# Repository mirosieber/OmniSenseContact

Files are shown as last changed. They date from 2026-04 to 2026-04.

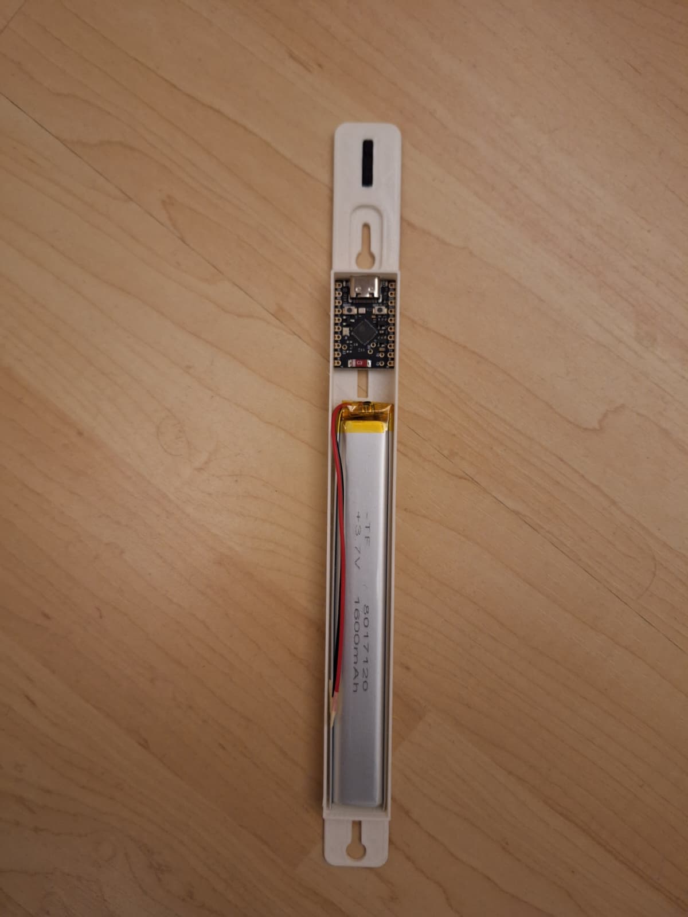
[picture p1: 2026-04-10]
Hardware/Bild1.jpeg

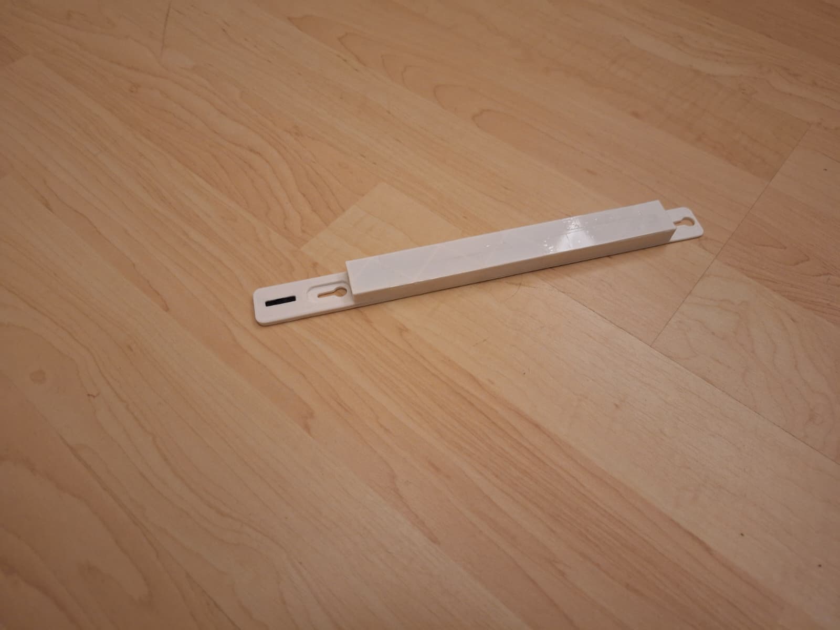
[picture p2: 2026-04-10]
Hardware/Bild2.jpeg

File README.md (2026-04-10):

# OmniSenseContact

A battery-powered Zigbee window/door contact sensor based on the ESP32-C6 Supermini with integrated 1S Li-Po charger.

## Overview

OmniSenseContact is a Zigbee-based window/door contact sensor for smart home automation. Built on the ESP32-C6 Supermini platform, it operates as a Zigbee End Device and communicates with your Zigbee coordinator (such as Home Assistant, Zigbee2MQTT, or other Zigbee hubs).

## Features

- **Zigbee Communication**: Native Zigbee 3.0 support via ESP32-C6
- **Binary Contact Sensor**: Reports open/closed state changes instantly
- **Battery Monitoring**: Real-time battery voltage and SoC reporting
- **Low Power Design**: Deep sleep mode with wake-up on state change or timer
- **Wake-up Sources**: Contact state change (GPIO interrupt), daily timer (24 hours), charger connection detection
- **Battery Protection**: Automatic shutdown at low battery (<10% SoC)

## Hardware Requirements

### Microcontroller
- **ESP32-C6 Supermini**: RISC-V based MCU with native Zigbee support and integrated 1S Li-Po charger
  - 160 MHz single-core processor
  - 512 KB SRAM
  - Built-in Zigbee 3.0 IEEE 802.15.4 radio

### Components
- **Battery**: 1S Li-Ion or Li-Po battery (3.7V nominal)
- **Contact Sensor**: **Normally Closed (NC)** magnetic reed switch or physical contact switch (required for energy efficiency)
- **Voltage Dividers**: For battery and charger detection
  - Battery monitoring: R1: 510kΩ, R2: 1MΩ
  - Charger detection: R1: 510kΩ, R2: 1MΩ

## Pin Configuration

| Pin | Function | Direction | Description |
|-----|---|---|---|
| GPIO 0 | Charger Detection | Input | HIGH when USB charger connected |
| GPIO 1 | Battery Voltage | Analog Input | Voltage divider output |
| GPIO 2 | Contact Sensor | Input (Pull-up) | LOW = closed, HIGH = open |
| GPIO 15 | Status LED | Output | Activity indicator |

## Software Requirements

- **ESP-IDF**: Version 4.1.0 or higher (tested with v5.x)
- **Arduino ESP32**: Version 3.3.2 (included as component)
- **CMake**: Version 3.5 or higher

### Required Components
- **ESP Zigbee SDK**: Included as git submodule

## Installation

### 1. Clone the Repository

```bash
git clone https://github.com/mirosieber/OmniSenseContact.git
cd OmniSenseContact
git submodule update --init --recursive
```

### 2. Install ESP-IDF

Follow the official ESP-IDF installation guide:
https://docs.espressif.com/projects/esp-idf/en/latest/esp32c6/get-started/

### 3. Build and Flash

```bash
idf.py build
idf.py -p /dev/ttyUSB0 flash monitor
```

Replace `/dev/ttyUSB0` with your serial port.

## Configuration

### Zigbee Configuration

```cpp
Manufacturer: "Miro Sieber"
Model: "OmniSenseContact"
Device Type: Binary Input (Contact Sensor)
Endpoint: 10
Power Source: Battery
```

### Network Settings

- **Connection Timeout**: 10 seconds
- **Report Timeout**: 1000ms per attribute
- **Max Retries**: 3 attempts
- **Deep Sleep Duration**: 86400 seconds (24 hours)

## Usage

### Pairing with Zigbee Coordinator

1. Put your Zigbee coordinator in pairing mode
2. Power on or reset the OmniSenseContact device
3. Wait up to 10 seconds for connection
4. First boot: Device waits 60 seconds for interview process

### Operation

- Device monitors contact sensor continuously
- Reports state changes instantly to coordinator
- Returns to deep sleep between events
- Daily automatic wake-up to maintain network presence

### Factory Reset

To re-pair with a new network:

```bash
idf.py erase-flash
idf.py flash
```

## Battery Management

### Voltage Monitoring

The device uses voltage dividers (510kΩ/1MΩ) to measure battery voltage and detect charger connection.

**Voltage Range:**
- Maximum: 4.2V (fully charged)
- Nominal: 3.7V
- Minimum: 3.0V
- Critical: Below 3.0V triggers permanent sleep

### State of Charge (SoC) Estimation

21-point voltage-to-SoC lookup table with linear interpolation and exponential filtering (80% old + 20% new).

### Battery Calibration

For accurate voltage readings:

1. Connect USB charger
2. Open serial monitor (115200 baud)
3. Measure actual battery voltage with multimeter
4. Enter measured voltage in serial console (e.g., `3.847`)
5. Calibration factor is saved to NVS

Type `s` to skip charging loop.
Type `reset` to factory reset the device.

### Low Battery Protection

When SoC < 10%:
- Device enters permanent deep sleep
- Only wakes when charger connected

## Power Management

**Active Time:** ~2-5 seconds per event
**Sleep Time:** Until next state change or 24-hour timer

**Wake-up Conditions:**
1. Contact state change (GPIO interrupt)
2. Daily timer (86400 seconds)
3. Charger connected

**Power Consumption:**
- Deep Sleep: ~10-20 µA
- Active (Zigbee TX): ~50-100 mA

## License



## Author

Miro Sieber

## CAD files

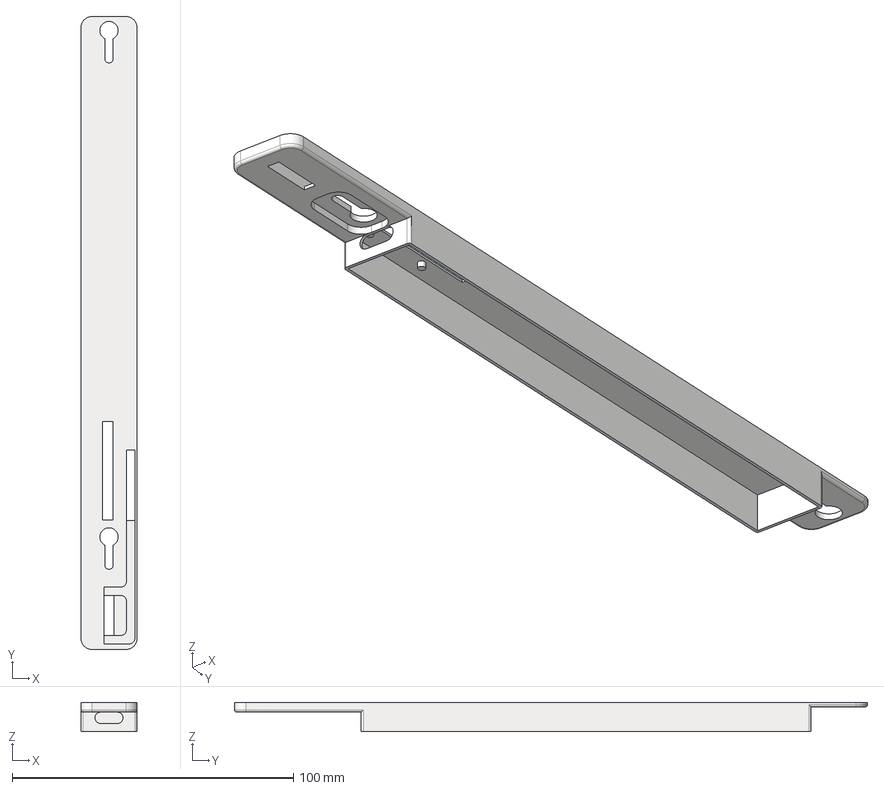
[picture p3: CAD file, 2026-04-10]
Hardware/Box.stp
20.0 x 225.0 x 10.4 mm

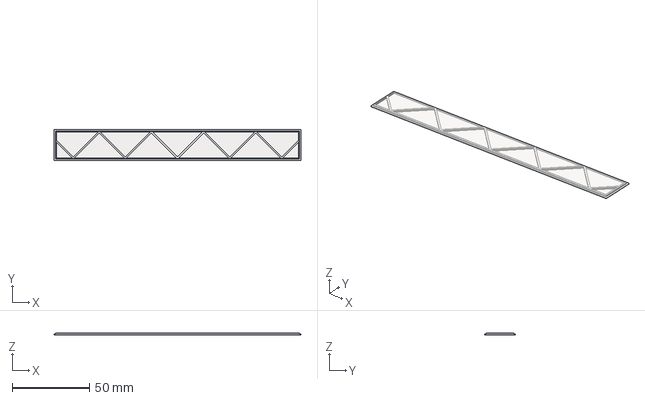
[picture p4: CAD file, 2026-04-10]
Hardware/Deckel.stp
160.0 x 20.0 x 1.50 mm

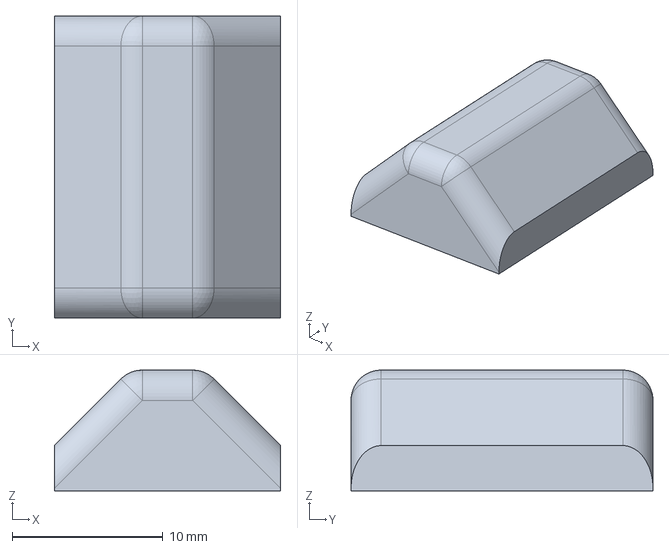
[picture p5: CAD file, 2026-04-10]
Hardware/Magnet Halter.stp
15.0 x 20.0 x 8.00 mm

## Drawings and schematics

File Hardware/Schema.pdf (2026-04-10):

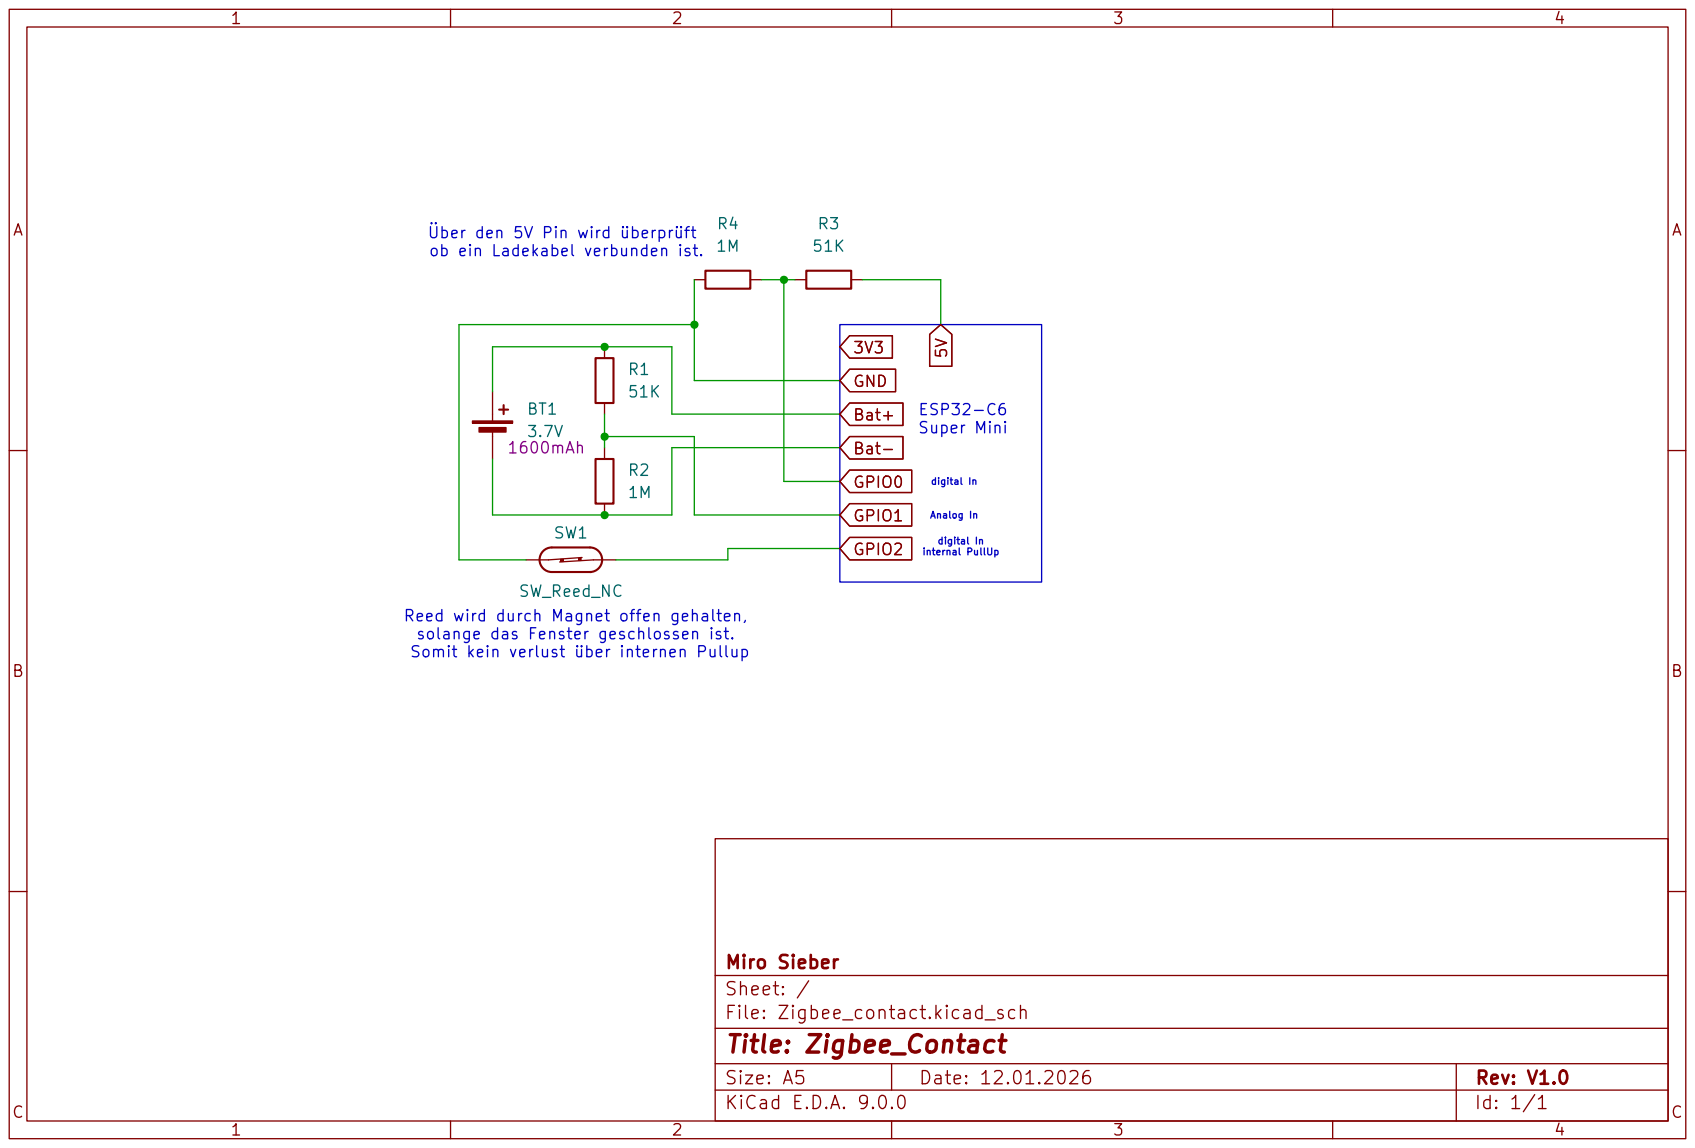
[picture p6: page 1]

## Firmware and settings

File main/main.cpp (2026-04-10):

#include "Arduino.h"
#include "Battery.h"
#include "Zigbee.h"
#include "driver/rtc_io.h"
#include "esp_app_format.h"
#include "esp_log.h"
#include "esp_pm.h"
#include "esp_sleep.h"
#include "esp_system.h"
#include "freertos/FreeRTOS.h"

// #define debug
//   zigbee debuging mus in menuconfig aktiviert werden

static const char *TAG = "OmniSenseContact";

#define CHARGER_CONNECTED_PIN                                                  \
  GPIO_NUM_0                     // Pin to detect if charger is connected
#define BATT_VOLT_PIN GPIO_NUM_1 // Pin to read battery voltage
#define CONTACT1_PIN GPIO_NUM_2  // Pin for contact sensor
#define CONTACT_SENSOR_ENDPOINT_NUMBER 10

#define CHARGER_CONNECTED_PIN_BITMASK (1ULL << CHARGER_CONNECTED_PIN)
#define CONTACT1_PIN_BITMASK (1ULL << CONTACT1_PIN)
/* Conversion factor for micro seconds to seconds */
#define uS_TO_S_FACTOR 1000000ULL
#define TIME_TO_SLEEP 86400 /* Sleep for max 1 day */
#define REPORT_TIMEOUT 1000 /* Timeout for response from coordinator in ms */
#define MAX_RETRIES 3       /* Max retries for sending data */
bool factoryReset = false;  // flag to indicate if factory reset is needed

ZigbeeBinary zbContact = ZigbeeBinary(CONTACT_SENSOR_ENDPOINT_NUMBER);

uint8_t dataToSend = 2; // Binary and Battery values are reported in same
                        // endpoint, so 2 values are reported
bool resend = false;    // flag to indicate data resend is needed

// tiefer als 80MHz und light sleep geht nicht, da Zigbee sonst nicht mehr läuft
void cpu_power_config(void) {
  esp_pm_config_t pm_config = {
      .max_freq_mhz = 80, .min_freq_mhz = 80, .light_sleep_enable = false};
  esp_pm_configure(&pm_config);
}

/************************ Callbacks *****************************/
// Global response callback to handle responses for all endpoints
void onGlobalResponse(zb_cmd_type_t command, esp_zb_zcl_status_t status,
                      uint8_t endpoint, uint16_t cluster) {
  ESP_LOGI(TAG,
           "Global response command: %d, status: %s, endpoint: %d, "
           "cluster: 0x%04x",
           command, esp_zb_zcl_status_to_name(status), endpoint, cluster);
  if ((command == ZB_CMD_REPORT_ATTRIBUTE) &&
      (endpoint == CONTACT_SENSOR_ENDPOINT_NUMBER)) {
    switch (status) {
    case ESP_ZB_ZCL_STATUS_SUCCESS:
      dataToSend--;
      break;
    case ESP_ZB_ZCL_STATUS_FAIL:
      resend = true;
      break;
    default:
      break; // add more statuses like ESP_ZB_ZCL_STATUS_INVALID_VALUE,
             // ESP_ZB_ZCL_STATUS_TIMEOUT etc.
    }
  }
}

bool initialBoot() {
  esp_sleep_wakeup_cause_t wakeup_reason = esp_sleep_get_wakeup_cause();
  return ((wakeup_reason == ESP_SLEEP_WAKEUP_UNDEFINED) || factoryReset);
}

void chargingLoop() {
  pinMode(15, OUTPUT);    // Onboard LED pin
  digitalWrite(15, HIGH); // Turn the LED on
  // Initialize Serial communication at 115200 baud
  Serial.begin(115200);
  delay(1000); // Wait for Serial to be ready
  Serial.printf("Git Repository: %s\n", GIT_REMOTE_URL);
  Serial.printf("Git Version:    %s\n", GIT_VERSION);
  Serial.printf("Git Branch:     %s\n", GIT_BRANCH);
  Serial.println("Charger connected, entering charging loop");
  while (digitalRead(CHARGER_CONNECTED_PIN)) {
    float VBatt = get_Vbatt(BATT_VOLT_PIN);
    uint8_t SOC = estimateSoC_filtered(VBatt);
    Serial.println();
    Serial.printf("Vbatt:          %.3f V, SoC: %d%%\n", VBatt, SOC);
    Serial.println("To calibrate battery Voltage please type in the accurate "
                   "voltage with 3 decimal accuracy:");

    for (int i = 0; i < 100; i++) {
      // Check if user has typed something send infos every 10 seconds
      if (Serial.available() > 0) {
        String userInput = Serial.readStringUntil('\n');
        userInput.trim();
        if (userInput.equalsIgnoreCase("s")) {
          Serial.println("Skipping charging as per user request.");
          return;
        }
        if (userInput.equalsIgnoreCase("reset")) {
          Serial.println("Resetting zigbee settings...");
          factoryReset = true;
          return;
        }
        float calibrationVoltage = userInput.toFloat();

        if (calibrationVoltage > 0 && calibrationVoltage < 5) {
          Serial.printf("Calibration voltage received: %.3f V\n",
                        calibrationVoltage);
          calculateVoltageCalibration(calibrationVoltage, BATT_VOLT_PIN);
          saveVoltageCalibration();
          Serial.println("Calibration complete.");
          break; // Exit the for loop after successful input
        } else {
          Serial.println(
              "Invalid voltage input. Please enter a value between 0 and 5V");
        }
      }
      delay(100); // check every 100ms for user input
    }
  }
  Serial.println("Charger disconnected / Battery full, exiting charging loop");
  Serial.end();
#ifndef debug
  // Disable UART0 (console)
  esp_log_level_set("*", ESP_LOG_NONE); // Disable all logs
  uart_driver_delete(UART_NUM_0);
  gpio_reset_pin(GPIO_NUM_16); // TX pin on ESP32-C6
  gpio_reset_pin(GPIO_NUM_17); // RX pin on ESP32-C6
#endif
}

/***************** Main application entry point ****************/

extern "C" void app_main(void) {
  cpu_power_config();
  initArduino();
#ifdef debug
  // Configure log levels for custom tags
  esp_log_level_set("*", ESP_LOG_INFO);
  esp_log_level_set("OmniSenseContact", ESP_LOG_INFO);
  esp_log_level_set("Battery", ESP_LOG_INFO);
#else
  // Disable UART0 (console)
  esp_log_level_set("*", ESP_LOG_NONE); // Disable all logs
  uart_driver_delete(UART_NUM_0);
  gpio_reset_pin(GPIO_NUM_16); // TX pin on ESP32-C6
  gpio_reset_pin(GPIO_NUM_17); // RX pin on ESP32-C6
#endif

  pinMode(CHARGER_CONNECTED_PIN, INPUT);
  pinMode(CONTACT1_PIN, INPUT_PULLUP);

  // Read binary sensor value
  bool contact = digitalRead(CONTACT1_PIN);
  ESP_LOGI(TAG, "Contact ist %s", contact ? "HIGH" : "LOW");

  battery_init(); // Initialize battery module (load calibration from NVS)

#ifdef debug
  pinMode(15, OUTPUT);    // Onboard LED pin
  digitalWrite(15, HIGH); // Turn the LED on
#endif

  // wenn device gets charged:
  if (digitalRead(CHARGER_CONNECTED_PIN)) {
    chargingLoop();
  }

  // set Zigbee device setup
  zbContact.setManufacturerAndModel("Miro Sieber", "OmniSenseContact");
  zbContact.addBinaryInput();
  zbContact.setPowerSource(ZB_POWER_SOURCE_BATTERY);
  zbContact.setBinaryInputApplication(
      BINARY_INPUT_APPLICATION_TYPE_SECURITY_INTRUSION_DETECTION);
  // Global callback for all endpoints with more params to determine the
  // endpoint and cluster in the callback function.
  Zigbee.onGlobalDefaultResponse(onGlobalResponse);
  // Add endpoint to Zigbee Core
  Zigbee.addEndpoint(&zbContact);

  // For battery powered devices, it can be better to set timeout for Zigbee
  // Begin to lower value to save battery If the timeout has been reached, the
  // network channel mask will be reset and the device will try to connect again
  // after reset (scanning all channels)
  // Set timeout for Zigbee Begin to 10s (default is 30s)
  Zigbee.setTimeout(10000);

  // When all EPs are registered, start Zigbee in End Device mode
  if (!Zigbee.begin(ZIGBEE_END_DEVICE, factoryReset)) {
    ESP_LOGE(TAG, "Zigbee failed to start!");
    ESP_LOGE(TAG, "Rebooting...");
    ESP.restart(); // If Zigbee failed to start, reboot the device and try again
  }
  // resave current voltage calibration factor to NVS after factory reset
  if (factoryReset) {
    saveVoltageCalibration();
  }

  while (!Zigbee.connected()) {
    ESP_LOGI(TAG, ".");
    delay(100);
  }
  ESP_LOGI(TAG, "Successfully connected to Zigbee network");
  if (initialBoot()) {
    ESP_LOGI(TAG,
             "Initial Boot detected wait 60 seconds until interview is done");
    delay(60000);
  } else {
    ESP_LOGI(TAG, "Wake up from Deep Sleep detected");
  }

  // Mesure Battery Voltage
  float VBatt = get_Vbatt(BATT_VOLT_PIN);
  uint8_t SOC = estimateSoC_filtered(VBatt);

  // Update values in the End Point
  zbContact.setBinaryInput(!contact);
  zbContact.setBatteryPercentage(SOC > 0 ? SOC : 1); // set min 1% to avoid 0%

  // Report values
  zbContact.reportBatteryPercentage();
  zbContact.reportBinaryInput();
  ESP_LOGI(TAG, "Reported Contact state: %s, Battery SOC: %d%%",
           contact ? "HIGH" : "LOW", SOC);

  unsigned long startTime = millis();
  const unsigned long timeout = REPORT_TIMEOUT;

  ESP_LOGI(TAG, "Waiting for data report to be confirmed");
  // Wait until data was successfully sent
  int tries = 0;
  while (dataToSend != 0 && tries < MAX_RETRIES) {
    if (resend) {
      ESP_LOGW(TAG, "Resending data on failure!");
      resend = false;
      dataToSend = 2;
      zbContact.reportBatteryPercentage();
      zbContact.reportBinaryInput(); // report again
    }
    if (millis() - startTime >= timeout) {
      ESP_LOGW(TAG, "Report timeout! Report Again");
      dataToSend = 2;
      zbContact.reportBatteryPercentage();
      zbContact.reportBinaryInput(); // report again
      startTime = millis();
      tries++;
    }
    // ESP_LOGI(TAG, ".");
    delay(10); // 50ms delay to avoid busy-waiting
  }

  if (SOC < 10) {
    ESP_LOGW(TAG, "Battery SOC is below 10%% Sleep forever to save battery");
    esp_sleep_enable_ext1_wakeup(CHARGER_CONNECTED_PIN_BITMASK,
                                 ESP_EXT1_WAKEUP_ANY_HIGH);
  } else {
    // Determan Wake up level so next wake up is wen contact is closed/open
    esp_sleep_ext1_wakeup_mode_t level_mode;
    uint64_t CONTACT_WAKE_MASK;
    if (contact) {
      ESP_LOGI(TAG, "Contact ist HIGH");
      ESP_LOGI(TAG, "Window is closed");
      CONTACT_WAKE_MASK = (CONTACT1_PIN_BITMASK);
      level_mode = ESP_EXT1_WAKEUP_ANY_LOW;
    } else {
      ESP_LOGI(TAG, "Contact ist LOW");
      ESP_LOGI(TAG, "Window is opened");
      CONTACT_WAKE_MASK =
          (CHARGER_CONNECTED_PIN_BITMASK | CONTACT1_PIN_BITMASK);
      level_mode = ESP_EXT1_WAKEUP_ANY_HIGH;
    }
    // IO wake up setzen
    esp_sleep_enable_ext1_wakeup(CONTACT_WAKE_MASK, level_mode);
    // Configure the wake up source and set to wake up every x days to stay
    // online
    esp_sleep_enable_timer_wakeup(TIME_TO_SLEEP * uS_TO_S_FACTOR);
  }
  // Put device to deep sleep after data was sent successfully or timeout
  ESP_LOGI(TAG, "Going to sleep now");
  rtc_gpio_hold_en(
      (gpio_num_t)CONTACT1_PIN); // hold GPIO state during deep sleep
  esp_deep_sleep_start();

  for (;;) {
    // should never be reached
    ESP_LOGE(TAG, "Error: Reached unreachable code, restarting...");
    delay(1000);
    ESP.restart();
  }
}

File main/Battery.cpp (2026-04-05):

#include "Battery.h"
#include "esp_log.h"
#include "nvs.h"
#include "nvs_flash.h"
#include <Arduino.h>

static const char *TAG = "Battery";
// Voltage divider resistors
constexpr float R1 = 510.0;
constexpr float R2 = 1000.0;
constexpr double DIVIDER = (R1 + R2) / R2;
constexpr double MV_TO_V = 0.001;
// k= soll Spannung(MultiM) / ist Spannung(ESP)
static float calibrationFactor = 1.0;
static double get_Vbatt_uncalibrated(gpio_num_t pin);

// Initialize battery module - load calibration factor from NVS
void battery_init() {
  nvs_handle_t nvs_handle;
  esp_err_t err = nvs_open("battery", NVS_READONLY, &nvs_handle);
  if (err == ESP_OK) {
    float stored_factor;
    size_t size = sizeof(float);
    err = nvs_get_blob(nvs_handle, "cal_factor", &stored_factor, &size);
    if (err == ESP_OK) {
      calibrationFactor = stored_factor;
      ESP_LOGI(TAG, "Loaded calibration factor from NVS: %.5f",
               calibrationFactor);
    } else {
      ESP_LOGI(TAG, "No stored calibration factor, using default: %.5f",
               calibrationFactor);
    }
    nvs_close(nvs_handle);
  } else {
    ESP_LOGI(TAG,
             "Could not open NVS for battery, using default calibration: %.5f",
             calibrationFactor);
  }
}

// battery voltage
float get_Vbatt(gpio_num_t pin) {
  double Vbattf = get_Vbatt_uncalibrated(pin) * calibrationFactor;
  return static_cast<float>(Vbattf);
}

static double get_Vbatt_uncalibrated(gpio_num_t pin) {
  // nur einmal messen, da sehr hochohmig, adc Kapazität braucht Zeit zum
  // Aufladen
  analogReadMilliVolts(pin); // Dummy
  delay(20);                 // Aufladen
  uint32_t mv = analogReadMilliVolts(pin);
  return mv * DIVIDER * MV_TO_V;
}

uint8_t estimateSoC_filtered(float voltage) {
  static float soc_filt = -1;

  uint8_t soc = estimateSoC(voltage);

  if (soc_filt < 0)
    soc_filt = soc;
  else
    soc_filt = 0.8f * soc_filt + 0.2f * soc;

  return (uint8_t)(soc_filt + 0.5f);
}

uint8_t estimateSoC(float voltage) {
  // Stützpunkte: Spannung (V) → Ladezustand (%)
  const float voltages[] = {4.20, 4.15, 4.11, 4.08, 4.02, 3.98, 3.95,
                            3.91, 3.87, 3.83, 3.82, 3.81, 3.80, 3.77,
                            3.76, 3.75, 3.73, 3.71, 3.69, 3.67, 3.27};

  const uint8_t socs[] = {100, 95, 90, 85, 80, 75, 70, 65, 60, 55, 50,
                          45,  40, 35, 30, 25, 20, 15, 10, 5,  0};

  const int numPoints = sizeof(voltages) / sizeof(voltages[0]);

  // Begrenzen auf gültigen Bereich
  if (voltage >= voltages[0])
    return 100;
  if (voltage <= voltages[numPoints - 1])
    return 0;

  // Lineare Interpolation zwischen den Stützpunkten
  for (int i = 0; i < numPoints - 1; i++) {
    float v1 = voltages[i];
    float v2 = voltages[i + 1];
    if (voltage <= v1 && voltage >= v2) {
      float soc1 = socs[i];
      float soc2 = socs[i + 1];
      float fraction = (voltage - v2) / (v1 - v2);
      float result = soc2 + fraction * (soc1 - soc2);

      // Rundung und Begrenzung auf 0–100 %
      if (result < 0)
        result = 0;
      if (result > 100)
        result = 100;
      return (uint8_t)(result + 0.5f);
    }
  }
  return 0; // sollte nie erreicht werden
}

void calculateVoltageCalibration(float accurateVoltage, gpio_num_t pin) {
  // Calculate calibration factor
  calibrationFactor = accurateVoltage / get_Vbatt_uncalibrated(pin);
  ESP_LOGI(TAG, "Calibration factor set to: %.5f", calibrationFactor);
}

void saveVoltageCalibration() {
  // Save to NVS
  nvs_handle_t nvs_handle;
  esp_err_t err = nvs_open("battery", NVS_READWRITE, &nvs_handle);
  if (err == ESP_OK) {
    err = nvs_set_blob(nvs_handle, "cal_factor", &calibrationFactor,
                       sizeof(float));
    if (err == ESP_OK) {
      err = nvs_commit(nvs_handle);
      if (err == ESP_OK) {
        ESP_LOGI(TAG, "Calibration factor saved to NVS");
      } else {
        ESP_LOGE(TAG, "Failed to commit calibration factor to NVS");
      }
    } else {
      ESP_LOGE(TAG, "Failed to write calibration factor to NVS");
    }
    nvs_close(nvs_handle);
  } else {
    ESP_LOGE(TAG, "Failed to open NVS for saving calibration factor");
  }
}

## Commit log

2025-10-27 changed to esp idf for delta ota suport
    [partitions.csv]
2025-10-27 Convert arduino-esp32-3.3.2 from submodule to normal folder
2025-10-28 v4 ota test print version
2026-01-09 disabled brown reset, v1 mit hardware
    [Battery.cpp, main.cpp]
2026-01-14 serial callibration and voltage indication while charging
2026-01-16 power optimiert, cpu freq gesänkt
2026-01-21 nur 1 mal reed sensor lesen, so dass jede änderung gesändet wird egal wie kurz das fenster offen ist
2026-01-22 Shorten README, fix resistor values, remove OTA, update to ESP32-C6 Supermini
2026-04-05 zigbee reset mit r hinzugefügt
    [Battery.cpp, main.cpp]
2026-04-10 reset nicht bei r sondern bei reset, readme angepasst. bei unter 10% wieder aufwachen wenn ladegerät angeschlossen
    [main.cpp]
2026-04-10 hardware infos
    [Box.stp, Deckel.stp, Magnet Halter.stp]

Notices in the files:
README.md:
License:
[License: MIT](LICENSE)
